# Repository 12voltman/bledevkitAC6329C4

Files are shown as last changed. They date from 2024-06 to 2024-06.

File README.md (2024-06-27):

# Dev board for the AC6329C4 from JieLi Tech
Able to be found for an astounding $0.25 in quantity [here](https://www.lcsc.com/product-detail/Microcontroller-Units-MCUs-MPUs-SOCs_JieLi-Tech-AC6329C4_C5440081.html), the AC6329C4 is a promising chip for ultra low cost BLE devices.  
Some of the cool features of this chip:  
- Integrated battery charger
- Integrated LDO for powering peripherals
- BLE 5.3 (may support further with new firmware)
- Full-speed USB OTG with built-in bootloader (needs weird trigger to enter DFU)
- 3 UARTs
- 1 I<sup>2</sup>C
- RTC
- 10-bit ADC w/ 6 channels
## Dev board features
This chip has some oddities around the bootloader, which needs a very specific bit pattern to be presented on the USB lines to enter DFU mode.  To enter DFU mode, I added an ATTINY microcontroller and a USB isolation switch, which also lets you use the USB pins as extra IOs if desired.

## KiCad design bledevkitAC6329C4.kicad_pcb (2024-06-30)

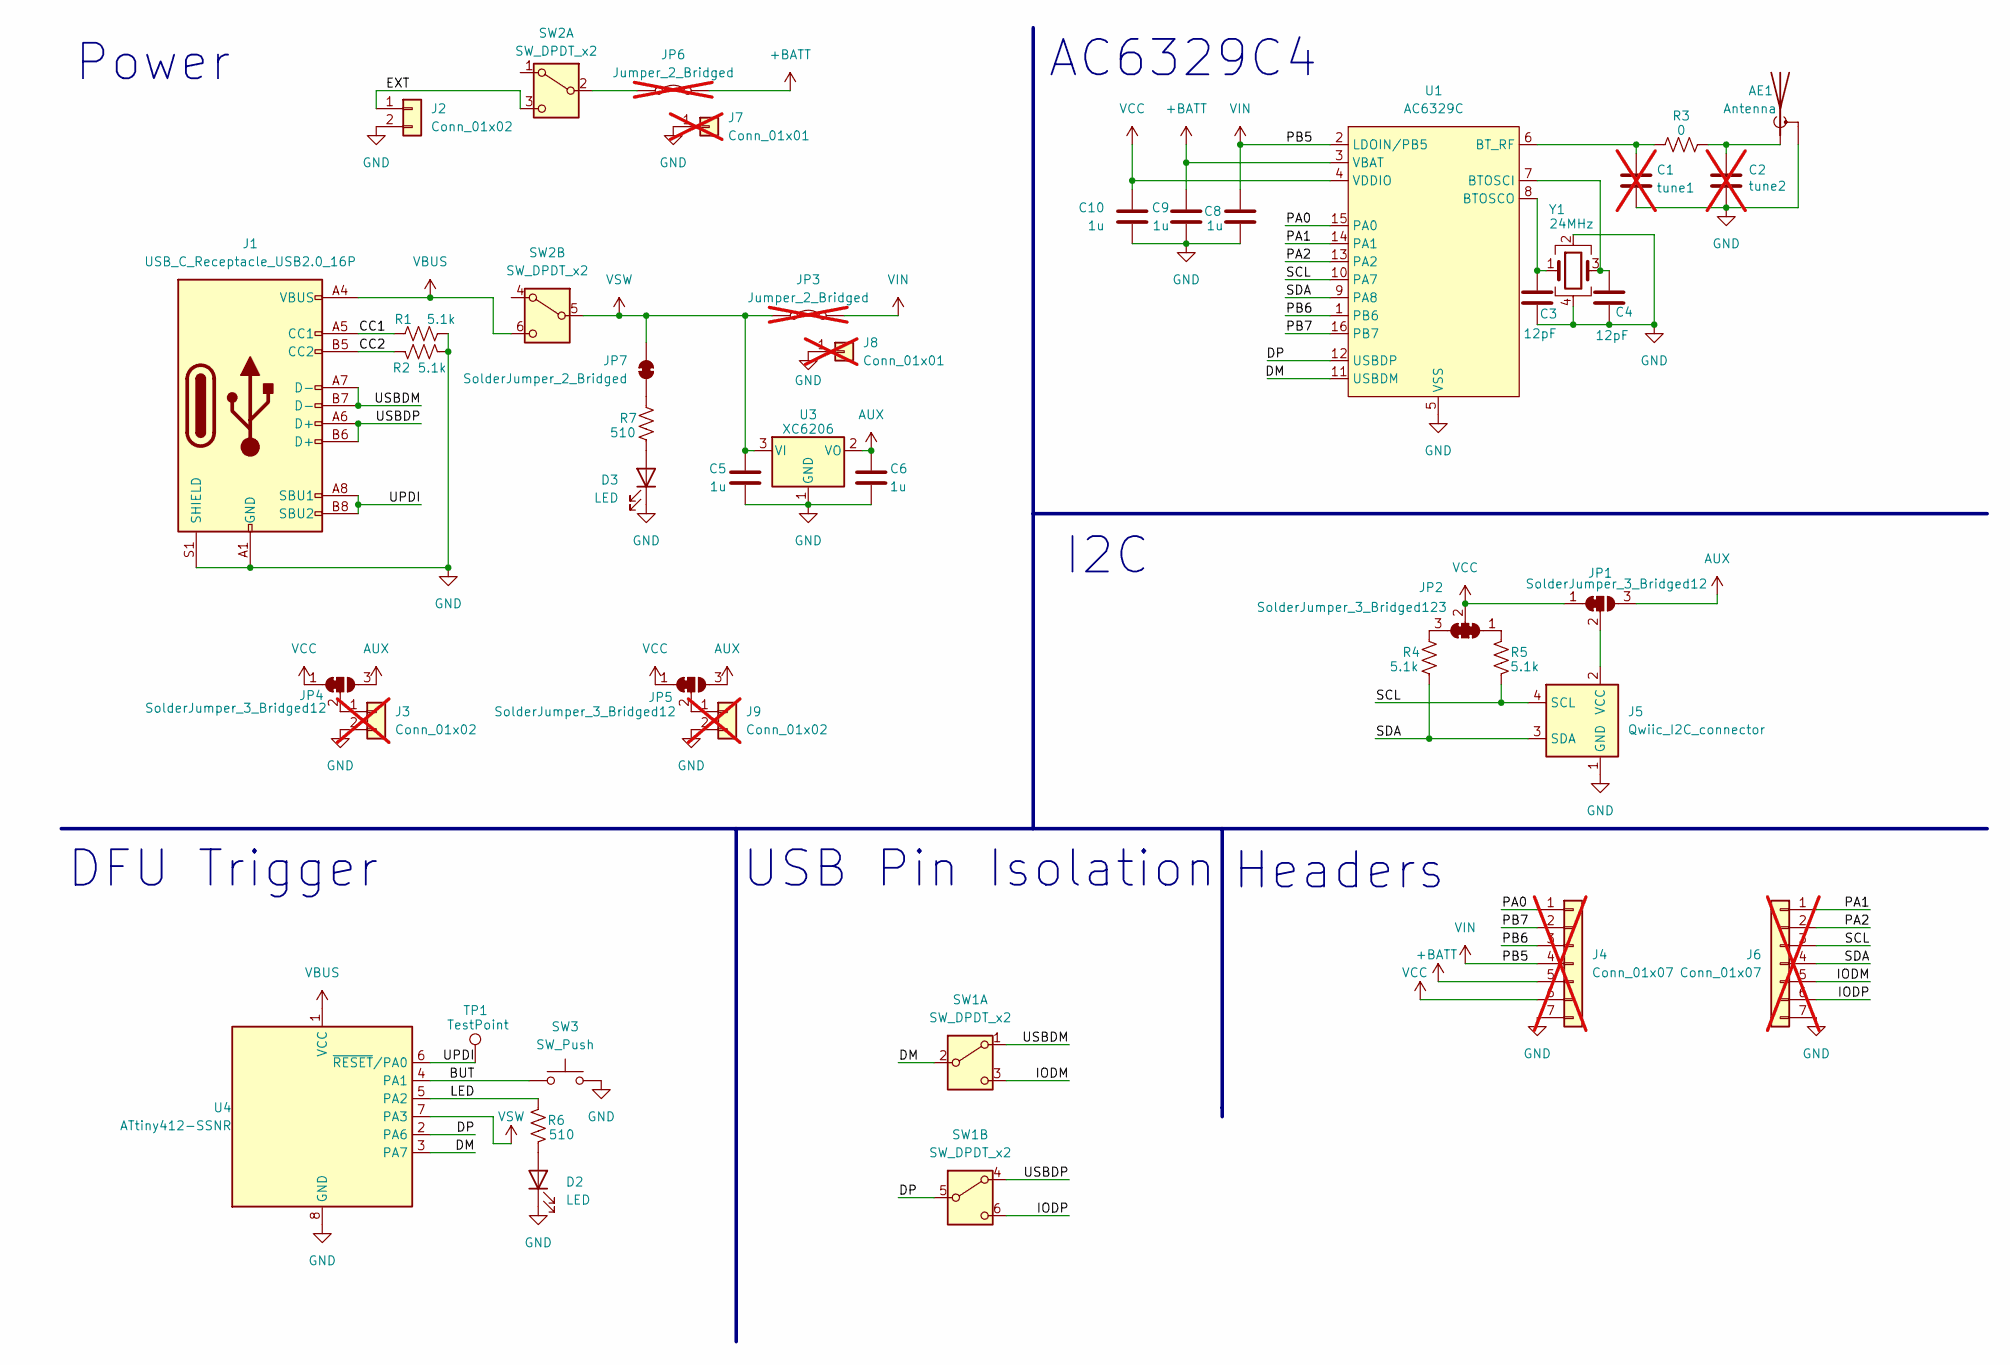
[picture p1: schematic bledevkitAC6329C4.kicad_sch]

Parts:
AE1: Antenna; Texas_SWRA117D_2.4GHz_Left
C1: tune1; C_0402_1005Metric; not fitted
C2: tune2; C_0402_1005Metric; not fitted
C3, C4: 12pF; C_0402_1005Metric; LCSC C1547
C5, C6, C8, C9, C10: 1u; C_0402_1005Metric; LCSC C52923
D2: LED; LED_0402_1005Metric; LCSC C2856703
D3: LED; LED_0402_1005Metric; LCSC C965790
J1: USB_C_Receptacle_USB2.0_16P; USB_C_Receptacle_HCTL_HC-TYPE-C-16P-01A; LCSC C2765186
J2: Conn_01x02; JST_PH_S2B-PH-SM4-TB_1x02-1MP_P2.00mm_Horizontal; LCSC C7433648
J3, J9: Conn_01x02; PinHeader_1x02_P2.54mm_Vertical; LCSC C492401; not fitted
J4, J6: Conn_01x07; PinHeader_1x07_P2.54mm_Vertical; LCSC C492406; not fitted
J5: Qwiic_I2C_connector; JST_SH_SM04B-SRSS-TB_1x04-1MP_P1.00mm_Horizontal; LCSC C7433440
J7, J8: Conn_01x01; PinHeader_1x01_P2.54mm_Vertical; LCSC C492400; not fitted
JP1, JP4, JP5: SolderJumper_3_Bridged12; SolderJumper-3_P1.3mm_Bridged12_RoundedPad1.0x1.5mm
JP2: SolderJumper_3_Bridged123; SolderJumper-3_P1.3mm_Bridged123_RoundedPad1.0x1.5mm
JP3, JP6: Jumper_2_Bridged; PinHeader_1x02_P2.54mm_Vertical; LCSC C492401; not fitted
JP7: SolderJumper_2_Bridged; SolderJumper-2_P1.3mm_Bridged_RoundedPad1.0x1.5mm
R1, R2, R4, R5: 5.1k; R_0402_1005Metric; LCSC C25905
R3: 0; R_0402_1005Metric; LCSC C17168
R6, R7: 510; R_0402_1005Metric; LCSC C25123
SW1, SW2: SW_DPDT_x2; DPDT-Slide_top; LCSC C2837066
SW3: SW_Push; TINYTACTILE; LCSC C455280
TP1: TestPoint; TestPoint_Pad_D3.0mm
U1: AC6329C; SOIC-16_3.9x9.9mm_P1.27mm; LCSC C5440081
U3: XC6206; SOT-23-3; LCSC C3015484
U4: ATtiny412-SSNR; SOIC-8_3.9x4.9mm_P1.27mm; LCSC C1337190
Y1: 24MHz; Crystal_SMD_3225-4Pin_3.2x2.5mm; LCSC C70590

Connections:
+BATT: C9.1, J4.5, JP6.2 (B), U1.3 (VBAT)
/BUT: SW3.1, U4.4 (PA1)
/CC1: J1.A5 (CC1), R1.1
/CC2: J1.B5 (CC2), R2.1
/DM: SW1.2 (B), U1.11 (USBDM), U4.3 (PA7)
/DP: SW1.5 (B), U1.12 (USBDP), U4.2 (PA6)
/EXT: J2.1, SW2.3 (C)
/IODM: J6.5, SW1.3 (C)
/IODP: J6.6, SW1.6 (C)
/LED: R6.2, U4.5 (PA2)
/PA0: J4.1, U1.15 (PA0)
/PA1: J6.1, U1.14 (PA1)
/PA2: J6.2, U1.13 (PA2)
/PB6: J4.3, U1.1 (PB6)
/PB7: J4.2, U1.16 (PB7)
/SCL: J5.4 (SCL), J6.3, R5.1, U1.10 (PA7)
/SDA: J5.3 (SDA), J6.4, R4.1, U1.9 (PA8)
/UPDI: J1.A8 (SBU1), J1.B8 (SBU2), TP1.1, U4.6 (~RESET/PA0)
/USBDM: J1.A7 (D-), J1.B7 (D-), SW1.1 (A)
/USBDP: J1.A6 (D+), J1.B6 (D+), SW1.4 (A)
AUX: C6.1, JP1.3 (B), JP4.3 (B), JP5.3 (B), U3.2 (VO)
GND: AE1.2 (Shield), C1.2, C2.2, C3.2, C4.2, C5.2, C6.2, C8.2, C9.2, C10.2, D2.1 (K), D3.1 (K), J1.A1 (GND), J1.A12 (GND), J1.B1 (GND), J1.B12 (GND), J1.S1 (SHIELD), J2.2, J3.2, J4.7, J5.1 (GND), J5.MP (VSS), J6.7, J7.1, J8.1, J9.2, R1.2, R2.2, SW3.2, U1.5 (VSS), U3.1 (GND), U4.8 (GND), Y1.2, Y1.4
unnamed: AE1.1 (A), C2.1, R3.2
unnamed: D2.2 (A), R6.1
unnamed: D3.2 (A), R7.1
unnamed: J3.1, JP4.2 (C)
unnamed: J5.2 (VCC), JP1.2 (C)
unnamed: J9.1, JP5.2 (C)
unnamed: JP2.1 (A), R5.2
unnamed: JP2.3 (B), R4.2
unnamed: JP6.1 (A), SW2.2 (B)
unnamed: JP7.2 (B), R7.2
unnamed: C4.1, U1.7 (BTOSCI), Y1.3
unnamed: C3.1, U1.8 (BTOSCO), Y1.1
unnamed: C1.1, R3.1, U1.6 (BT_RF)
VBUS: J1.A4 (VBUS), J1.A9 (VBUS), J1.B4 (VBUS), J1.B9 (VBUS), SW2.6 (C), U4.1 (VCC)
VCC: C10.1, J4.6, JP1.1 (A), JP2.2 (C), JP4.1 (A), JP5.1 (A), U1.4 (VDDIO)
VIN: C8.1, J4.4, JP3.2 (B), U1.2 (LDOIN/PB5)
VSW: C5.1, JP3.1 (A), JP7.1 (A), SW2.5 (B), U3.3 (VI), U4.7 (PA3)

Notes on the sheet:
DFU Trigger
Power
AC6329C4
I2C
USB Pin Isolation
Headers

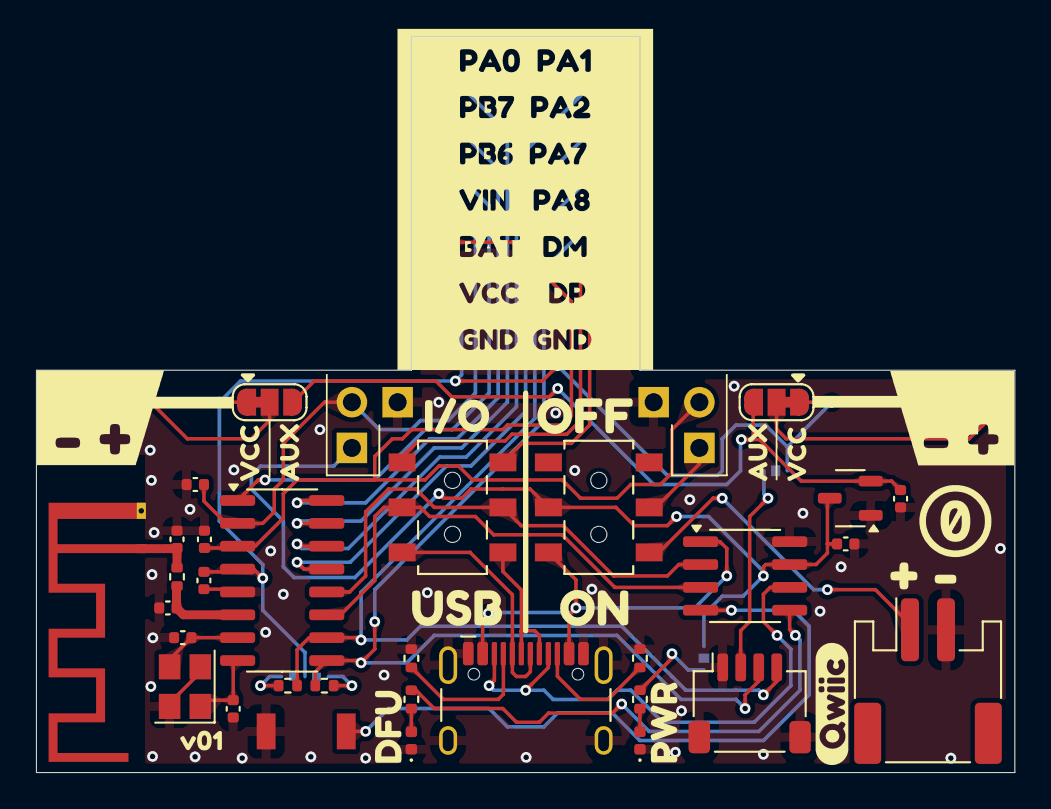
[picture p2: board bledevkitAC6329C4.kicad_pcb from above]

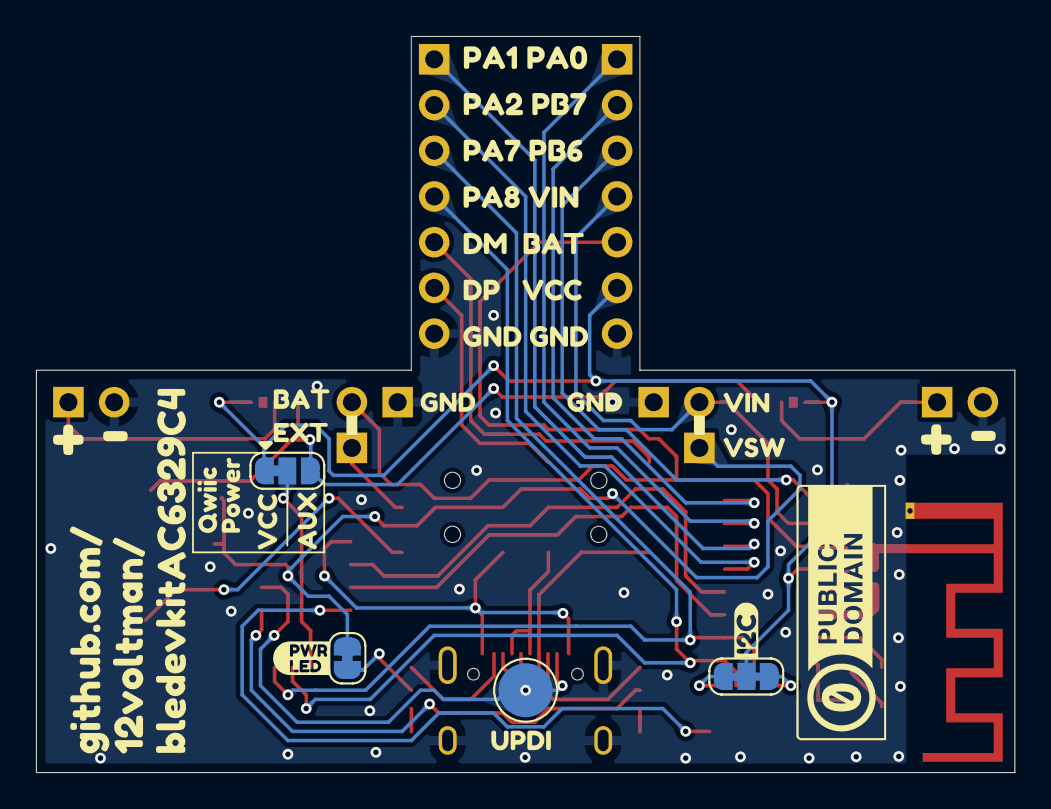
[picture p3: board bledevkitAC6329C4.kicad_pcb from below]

Board: 2 copper layers, 54.4 x 40.9 mm, 70 parts (21 on the bottom side), 39 nets.

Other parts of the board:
kibuzzard-667FBBEE: G***; kibuzzard-667FBBEE
kibuzzard-667FBC34: G***; kibuzzard-667FBC34
kibuzzard-6680A94E: G***; kibuzzard-6680A94E
kibuzzard-6680A820: G***; kibuzzard-6680A820
kibuzzard-6680AAC4: G***; kibuzzard-6680AAC4
kibuzzard-6680ABE0: G***; kibuzzard-6680ABE0
kibuzzard-6680AC8C: G***; kibuzzard-6680AC8C
kibuzzard-6680AE53, kibuzzard-6680AE53#2: G***; kibuzzard-6680AE53
kibuzzard-6680B7C1: G***; kibuzzard-6680B7C1
kibuzzard-6680B7CF: G***; kibuzzard-6680B7CF
kibuzzard-6680B177: G***; kibuzzard-6680B177
kibuzzard-6680BA41: G***; kibuzzard-6680BA41
kibuzzard-6680BA59: G***; kibuzzard-6680BA59
kibuzzard-6680BEA0: G***; kibuzzard-6680BEA0
kibuzzard-6680DFC0, kibuzzard-6680DFC0#2: G***; kibuzzard-6680DFC0
kibuzzard-6680E09B: G***; kibuzzard-6680E09B
kibuzzard-66809CDB: G***; kibuzzard-66809CDB
kibuzzard-66809CF2: G***; kibuzzard-66809CF2
kibuzzard-66809D04: G***; kibuzzard-66809D04
kibuzzard-66809D9A: G***; kibuzzard-66809D9A
kibuzzard-66809D18: G***; kibuzzard-66809D18
kibuzzard-66809D78: G***; kibuzzard-66809D78
kibuzzard-66809DBE: G***; kibuzzard-66809DBE
kibuzzard-66809E23, kibuzzard-66809E23#2: G***; kibuzzard-66809E23

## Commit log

2024-06-27 Initial PCB commit WIP
    [bledevkitAC6329C4.kicad_pcb, bledevkitAC6329C4.kicad_sch]
2024-06-28 Finalized power topology
    Isolated all power draws other than AC6329 behind current probe point. Added auxiliary 3.3V regulator as an option for Qwiic header. Shouldn't need any schematic changes, just on to making things fit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
    [bledevkitAC6329C4.kicad_pcb, bledevkitAC6329C4.kicad_sch]
2024-06-29 Finalized switches, chose modern DFU trigger
    Switched to the newest series of the ATTINY line for UPDI programming, which can be done over the USB-C connector for simplicity of flashing. Also made custom footprints for SMD DPDT slide switches. 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
    [bledevkitAC6329C4.kicad_pcb, bledevkitAC6329C4.kicad_sch]
2024-06-30 Finished routing
    [bledevkitAC6329C4.kicad_pcb, bledevkitAC6329C4.kicad_sch]
2024-06-30 Initial BOM and Finalized graphics
    [bledevkitAC6329C4.kicad_pcb, bledevkitAC6329C4.kicad_sch]
2024-06-30 Started DFM optimization
    [bledevkitAC6329C4.kicad_pcb, bledevkitAC6329C4.kicad_sch]
